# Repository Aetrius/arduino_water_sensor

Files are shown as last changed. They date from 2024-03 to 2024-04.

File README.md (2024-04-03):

# DIY Water Sensor Project

DIY Water Sensor Project for the techy folk. Utilizes fairly cheap equipment that allows you to replicate this project multiple times for multiple purposes.

This project utilizes the resistance the water creates on the water sensor to detect how high the water has ran up the sensor. You can generally look at the output and determine less than 10 as being nearly zero, while the water resistance can be upwards of 500 when the water level is high. This project can be powered by the battery OR powered via USB-C OR both USB-C plus battery for a battery backup.

## Hardware Required
- WeMos D1 Mini V4.0.0 Type-C USB WiFi
- USB Type C Wall Charger Plug 5V 1A
- 5V 1A TP4056 Charging Module Type-C USB 18650 Lithium Battery Charger Board with Protection (Type-C USB)
- Rain Water Level Sensor Module Depth Detection Liquid Surface Height for Arduino Raspberry Pi
- 3.7V 5200mah Rechargeable Battery Pack Lithium Ion Batteries with JST-2P
- JST Connector 2 Pin with Silicone Wire Cable 150mm
- Breadboards + Cables 
- Soldering Tools & Equipment

## Features

- USB-C Friendly
- Low Power Consumption with Sleep Mode
- Easily Configurable Arduino Code for Wifi / MQTT / Sleep
- Periodic [30s] polling to publish to MQTT Server.
- Built-in docker-compose scripting to build Prometheus/Grafana stack.

## Wiring Setup
In the wiring diagram below, we can see the following requirements:

- **Wemos D1 Mini (D2) RST** ==> **Wemos D1 Mini (D2) GPIO 16**
- **Wemos D1 Mini (D2) GPIO 12** ==> **Water Sensor (Positive)**
- **Wemos D1 Mini (D2) Power (3.3V)** ==> **USB-C Charger B+ (outside power pin)**
- **Wemos D1 Mini (D2) (Ground)** ==> **Water Sensor (Ground)**
- **Wemos D1 Mini (D2) (Ground)** ==> **USB-C Charger (Outside Ground pin)**
- **USB-C Charger B+ (inside power pin)** ==> **Battery Power Pin**
- **USB-C Charger B- (inside ground pin)** ==> **Battery Ground Pin**
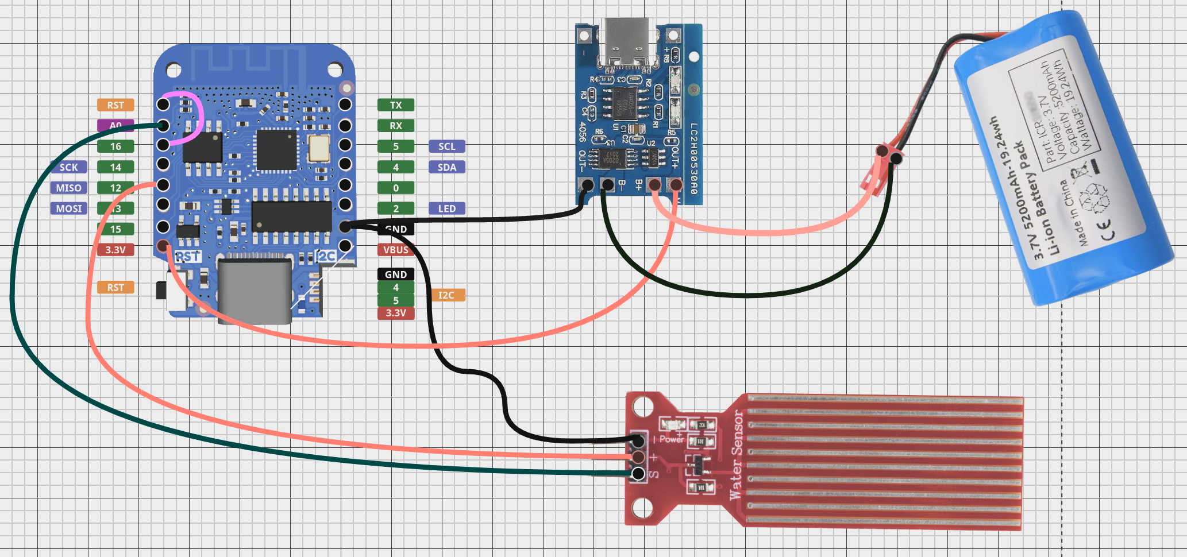
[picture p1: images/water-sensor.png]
Water Sensor


## Environment - Secret Variables

`WIFI_SSID` - WIFI network name for your wireless network.

`WIFI_PASSWORD` - Wireless Password

`MQTT_PUBLISH_TOPIC` - MQTT Topic Name, VERY important you name this per device. I'd suggest using this to name your device. Such as `sump_pump_basement`

`MQTT_SERVER` - IP / Hostname of your MQTT Server / VM

`MQTT_USER` - If applicable, username of the MQTT user account to publish data to the server. Leave an empty string or placeholder text if the user is not required.
 
`MQTT_PASSWORD` - If applicable, the password of the MQTT user account to publish data to the server. Leave an empty string or placeholder text if the user is not required.

## Installation

### Arduino Setup

Install the dependencies in order to run the Arduino code.

- Add the following Libraries to the Arduino IDE in preferences -> Additional Board Manager URLs.

    - `https://arduino.esp8266.com/stable/package_esp8266com_index.json`

    - `https://raw.githubusercontent.com/espressif/arduino-esp32/gh-pages/package_esp32_dev_index.json`

- Connect your USB-C cable to your computer, and choose the COM Port for your device. Then select the board `LOLIN (WEMOS) D1 R2 & Mini`. 

### Case - 3D Printable
See the images below for the fusion 360 generated views. The case snaps together snugly so it should hold up well.
The folder [stls] contains the stl printable files you can use. In my case I printed without supports using an X1C, flipping the parts on the appropriate faces to avoid supports.
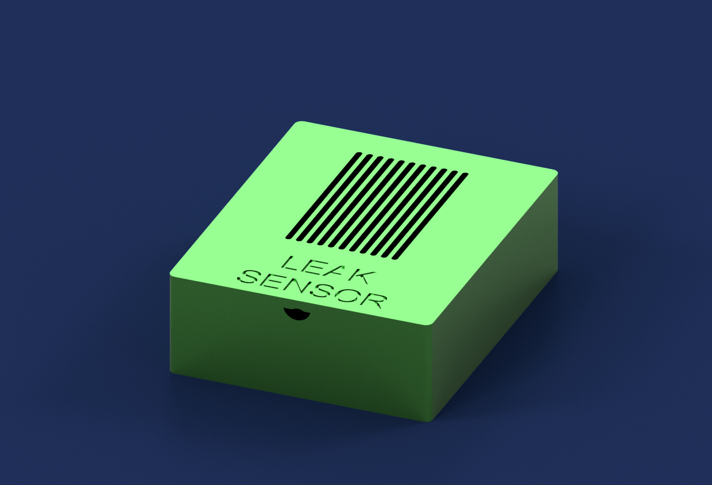
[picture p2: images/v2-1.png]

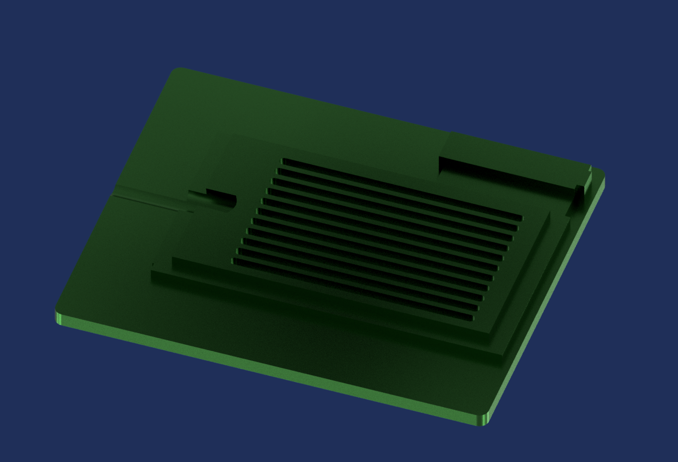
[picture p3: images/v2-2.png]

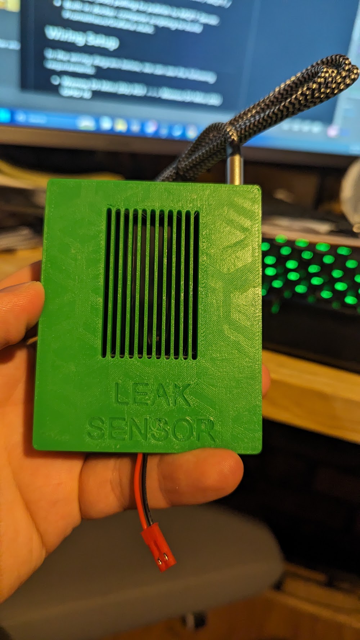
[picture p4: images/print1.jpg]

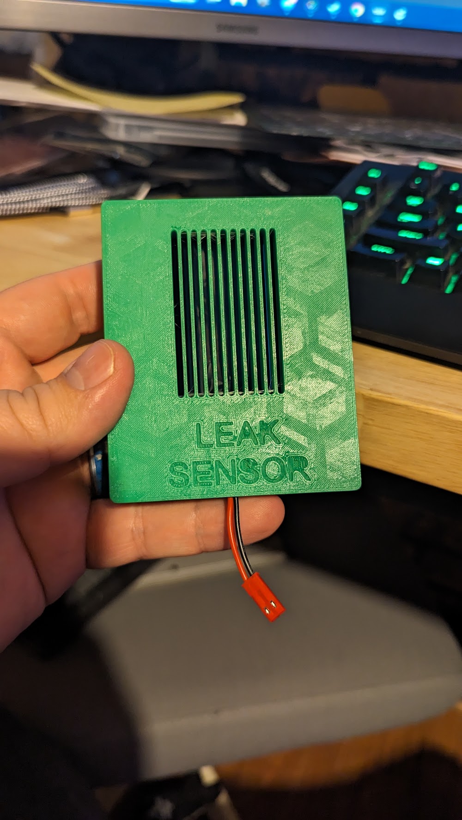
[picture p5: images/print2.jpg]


### Monitoring Stack Setup
Apply the steps below for your OS. I'm using a Virtualized Ubuntu, but you can lookup steps for any OS you want to run this on. Alternatively, you can throw this project into Kubernetes which I may do later on.

#### Ubuntu - Install Scripts
```bash
  sudo apt install docker
  sudo apt install docker-compose
  
```
## Deployment

To deploy MQTT + MQTT Exporter + Prometheus + Grafana run

```bash
  docker-compose -f ./monitoring-compose.yml up -d

```

## Authors

- [@Aetrius](https://www.github.com/aetrius)
- [@SmartThingsDIY](https://github.com/SmartThingsDIY/wemos-water-leak-sensor)

## Acknowledgements
This project was cloned from [SmartThingsDIY](https://github.com/SmartThingsDIY/wemos-water-leak-sensor?tab=readme-ov-file) with some significant modifications.

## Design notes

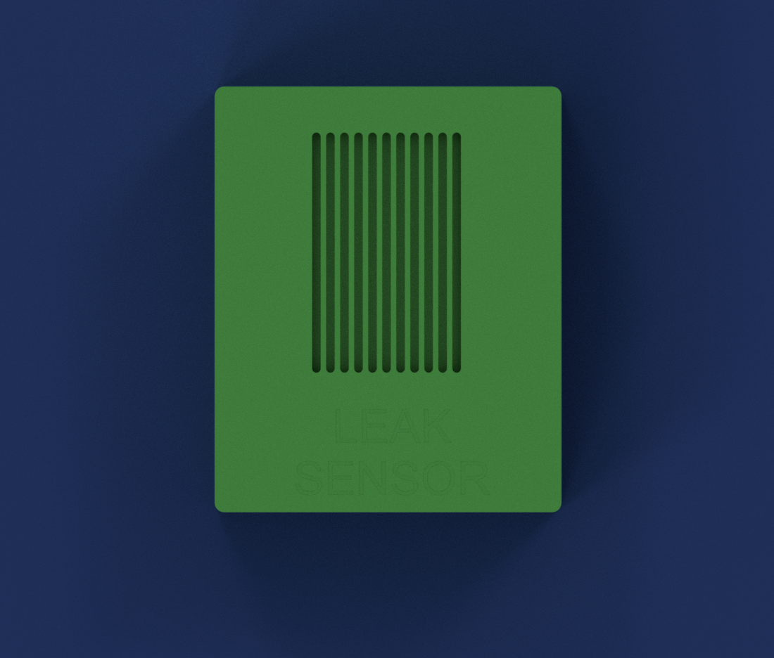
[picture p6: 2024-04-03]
images/v2-4.png

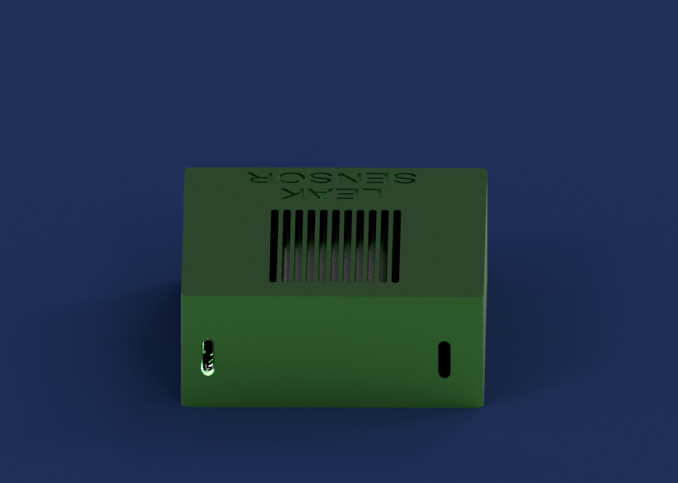
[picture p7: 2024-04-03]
images/v3-3.png

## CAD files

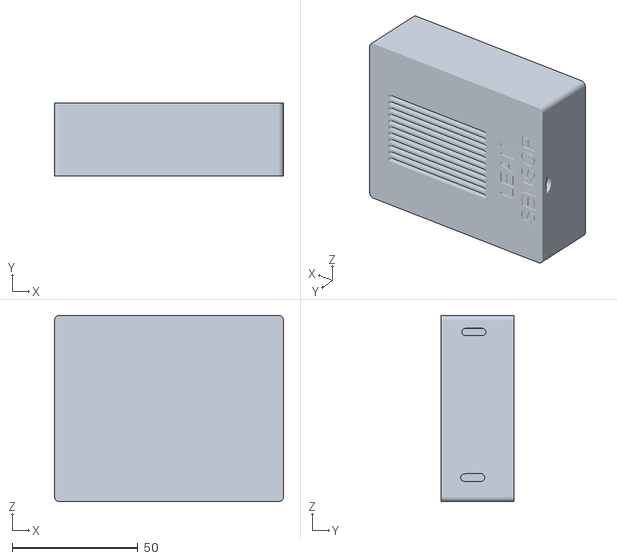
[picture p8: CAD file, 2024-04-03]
stls/WATER SENSOR WITH LID v12.stl
91.2 x 29.0 x 74.2

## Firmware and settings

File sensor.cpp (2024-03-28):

#include <Arduino.h>
#include "secrets.h"
#include <ESP8266WiFi.h>
#include <PubSubClient.h>
#include <Ticker.h>

#define DEBUG true // switch to "false" for production
Ticker ticker;
WiFiClient espClient;
PubSubClient client(espClient);

#define sensorPower D6 // Power pin (GPIO 12)
#define sensorPin A0 // Analog Sensor pin (example pin A0)
#define durationSleep 30 // seconds
#define NB_TRYWIFI 20 // WiFi connection retries

int sensorData = 0;

// **************
void tick();
void loop();
void setup();
int readSensor();
void connectToHass();
void connectToWiFi();
void publishAlarmToHass(int waterLevel);
// **************

void tick()
{
    // toggle state
    int state = digitalRead(LED_BUILTIN);  // get the current state of LED_BUILTIN pin
    digitalWrite(LED_BUILTIN, !state);     // set pin to the opposite state
}

/**
 * This is a function used to get the reading
 * @return
 */
int readSensor()
{
    // Step 1: Turn the sensor ON by providing power to sensorPower pin
    digitalWrite(sensorPower, HIGH);
    // Step 2: Wait for a short moment
    delay(10);
    // Step 3: Perform the reading
    sensorData = analogRead(sensorPin);
    // Step 4: Turn the sensor OFF
    digitalWrite(sensorPower, LOW);

    return sensorData;
}

/**
 * Establishes WiFi connection
 * @return
 */
void connectToWiFi()
{
    int _try = 0;
    WiFi.mode(WIFI_STA);

    IPAddress ip(192, 168, 2, 67);  // Define the desired IP address
    IPAddress gateway(192, 168, 1, 1);  // Define the gateway address
    IPAddress subnet(255, 255, 255, 0);  // Define the subnet mask

    WiFi.config(ip, gateway, subnet);

    WiFi.begin(WIFI_SSID, WIFI_PASSWORD);

    if (DEBUG == true) {
        Serial.println("Connecting to Wi-Fi");
    }

    while (WiFi.status() != WL_CONNECTED) {
        delay(500);
        Serial.print(".");
        _try++;
        if (_try >= NB_TRYWIFI) {
            if (DEBUG == true) {
                Serial.println("Impossible to connect WiFi, going to deep sleep");
            }
            // ESP.deepSleep(durationSleep * 1000000);
        }
    }

    if (DEBUG == true) {
        Serial.println("Connected to Wi-Fi");
        Serial.print("IP Address: ");
        Serial.println(WiFi.localIP());
    }
}

/**
 * Establishes connection to Home Assistant MQTT Broker
 * @return
 */
void connectToHass()
{
    client.setServer(MQTT_SERVER, 1883);

    // Loop until we're reconnected
    while (!client.connected()) {
        if (DEBUG == true) {
            Serial.print("Attempting MQTT connection...");
        }
        // Attempt to connect
        // If you do not want to use a username and password, change the next line to
        // if (client.connect("ESP8266Client")) {
        if (client.connect("ESP8266Client", MQTT_USER, MQTT_PASSWORD)) {
            if (DEBUG == true) {
                Serial.println("connected");
            }
        } else {
            if (DEBUG == true) {
                Serial.print("failed, rc=");
                Serial.print(client.state());
                Serial.println(" try again in 5 seconds");
            }
            // Wait 5 seconds before retrying
            delay(5000);
        }
    }
}

/**
 * Publishes notification to MQTT topic
 * @return
 */
void publishAlarmToHass(int waterLevel)
{
    // Create JSON string
    String json = "{\"water_level\": " + String(waterLevel) + "}";

    // Publish the JSON string to Hass through MQTT
    client.publish(MQTT_PUBLISH_TOPIC, json.c_str(), true);
    client.loop();
    if (DEBUG == true) {
        Serial.println("Alarm sent to Hass!");
    }
}

void setup()
{
    Serial.begin(115200);
    // Only print debug messages to serial if we're in debug mode
    //if (DEBUG == true) {
    delay(100);
    digitalWrite(LED_BUILTIN, LOW); // Turns the LED on
    Serial.print("D1 Mini V4.0.0 Waking up...");
    //}

    // Step 1: Set sensorPower pin as an output pin ready to receive power
    pinMode(sensorPower, OUTPUT);
    digitalWrite(sensorPower, LOW);

    // Step 2: Attach ticker to toggle LED_BUILTIN every 0.5 seconds
    ticker.attach(0.5, tick);
    delay(1000); // Wait for a second
    digitalWrite(LED_BUILTIN, HIGH);  // LED Pin set to High to turn on
    // Configure GPIO 16 with internal pull-up resistor
    pinMode(16, INPUT_PULLUP);

    // Set GPIO 16 LOW to trigger a reset when waking up
    digitalWrite(16, LOW);

    // Step 3: Wake the sensor up and get a reading
    int waterLevel = readSensor();

    if (DEBUG == true) {
        Serial.print("Water Level: ");
        Serial.println(waterLevel);
    }

    // Step 4: If water is detected then
    connectToWiFi(); // 1- connect to WiFi
    connectToHass(); // 2- connect to Home Assistant MQTT broker
    publishAlarmToHass(waterLevel); // 3- publish the water level on the MQTT topic

    // Step 5: Turn off power to sensor before going to sleep
    digitalWrite(sensorPower, LOW);

    if (DEBUG == true) {
        Serial.println("Finished run... Waiting to execute again...");
    }

    // Step 6: Go back to sleep for the next 5 seconds
    ESP.deepSleep(durationSleep * 1000000);
}

void loop()
{
  // Code inside loop function should never execute
  // as the ESP8266 will go to sleep after setup.
  // This function is just a placeholder and will never be executed.
}
